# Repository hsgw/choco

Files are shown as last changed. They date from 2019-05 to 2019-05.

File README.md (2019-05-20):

# CHOCO

choco

7x4 ortholinear onehanded keyboard/macropad.   

- kailh choc switch (pg1350)
- USB type-c
- STM32F072C8T6
- QMK Firmware - https://github.com/hsgw/qmk_firmware/tree/choco

## BUILD
### Cut mounting leg (SW_CHOC6)
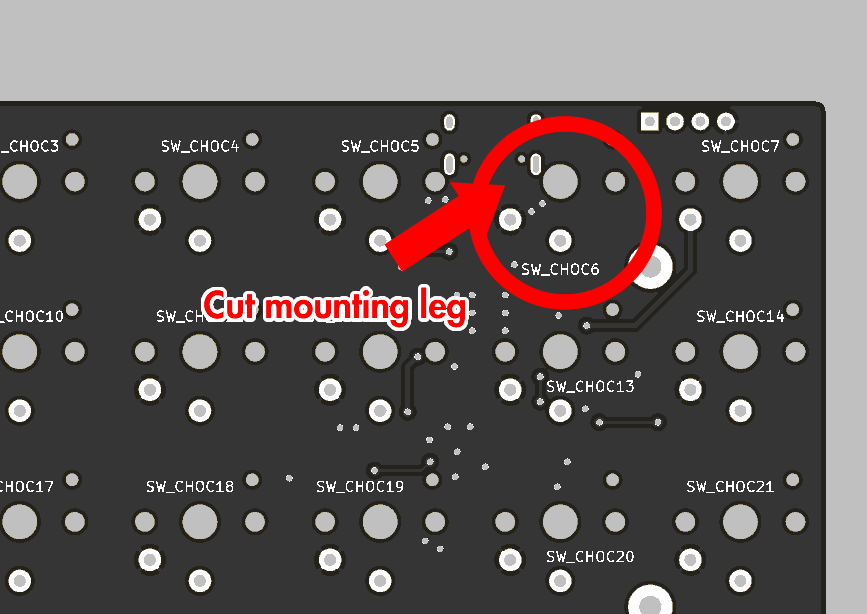
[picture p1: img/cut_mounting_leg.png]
cut_mounting_leg


### How to enter bootloader
1. Push and hold reset switch
2. Push and hold boot switch (SW_CHOC7 / right upper corner switch)
3. Release reset switch
4. Release boot switch

### Firmware
QMK Firmware - https://github.com/hsgw/qmk_firmware/tree/choco

## License
MIT license   
(c)2019 Takuya Urakawa, Dm9Records

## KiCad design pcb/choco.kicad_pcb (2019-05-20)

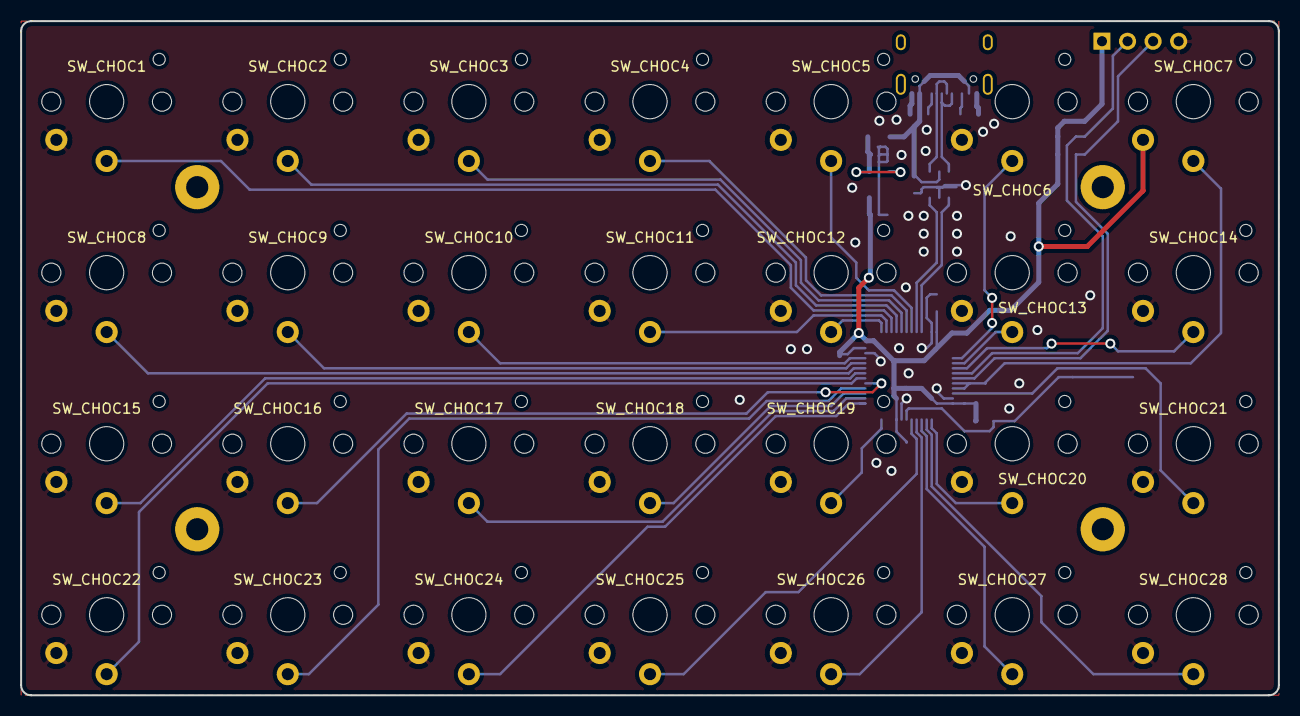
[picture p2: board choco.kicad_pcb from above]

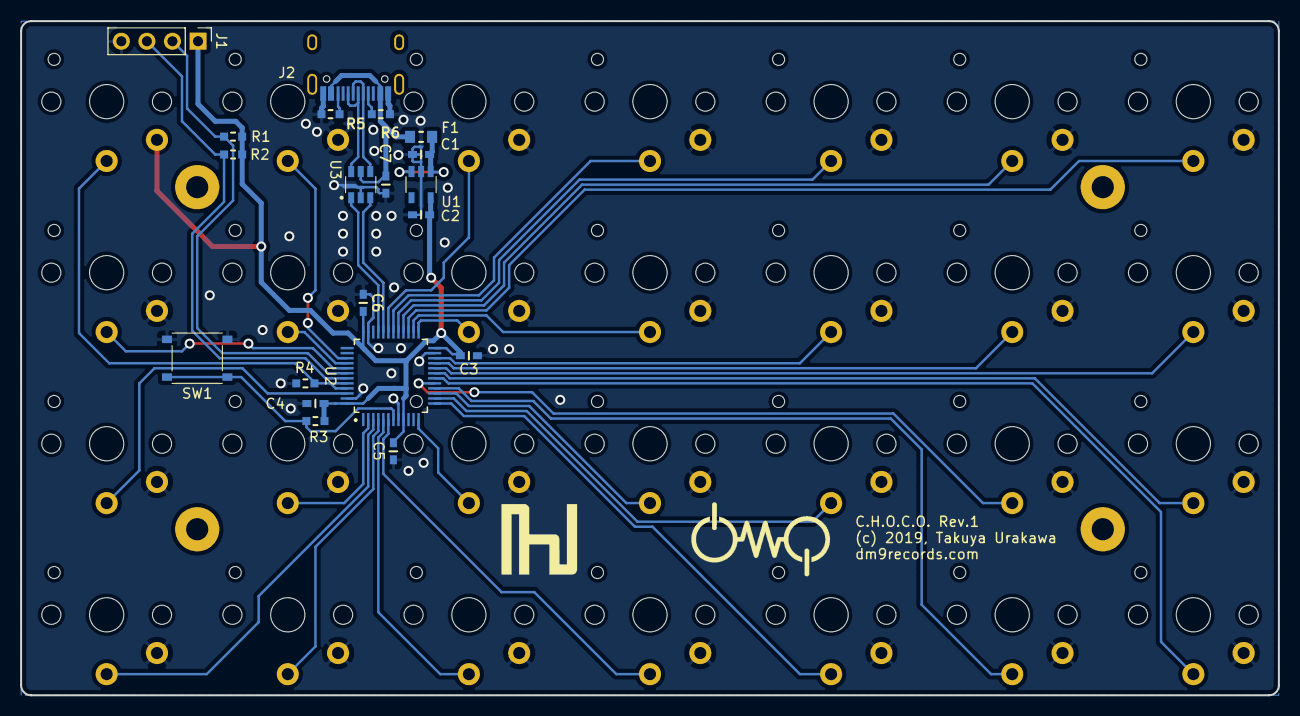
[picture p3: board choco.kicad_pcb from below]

Board: 2 copper layers, 125.0 x 67.0 mm, 48 parts (20 on the bottom side), 41 nets.

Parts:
C1, C2: 1u; C1608_Hand
C3, C4, C5, C6, C7: 0.1u; C1608_Hand
F1: 100mA; C2012_hand
J1: Conn_01x04; Socket_Strip_Straight_1x04_Pitch2.54mm
J2: USB_C_12pin_Receptacle; HRO-TYPE-C-31-M-12-Assembly
R1, R2: I2C; R1608_Hand
R3, R4: 10k; R1608_Hand
R5, R6: 5.1k; R1608_Hand
SW1: SW_Push; TACT_5.1x5.1
SW_CHOC1, SW_CHOC2, SW_CHOC3, SW_CHOC4, SW_CHOC5, SW_CHOC6, SW_CHOC7, SW_CHOC8, SW_CHOC9, SW_CHOC10, SW_CHOC11, SW_CHOC12, SW_CHOC13, SW_CHOC14, SW_CHOC15, SW_CHOC16, SW_CHOC17, SW_CHOC18, SW_CHOC19, SW_CHOC20, SW_CHOC21, SW_CHOC22, SW_CHOC23, SW_CHOC24, SW_CHOC25, SW_CHOC26, SW_CHOC27, SW_CHOC28: SW_Push; SW_kailh_pg1350_1u
U1: TLV73333PDBVR; SOT-23-5
U2: STM32F072C8Tx; LQFP-48_7x7mm_Pitch0.5mm
U3: USBLC6-2SC6; SOT-23-6

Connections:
+3V3: C2.1, C3.1, C4.1, C5.1, C6.1, J1.1, R1.1, R2.1, R3.1, SW_CHOC7.2, U1.5, U2.9, U2.24, U2.36, U2.48
/BOOT: R4.1, SW_CHOC7.1, U2.44, U2.45
/I2C_SCL: J1.2, R1.2, U2.42
/I2C_SDA: J1.3, R2.2, U2.43
/SW1: SW_CHOC1.1, U2.27
/SW2: SW_CHOC2.1, U2.28
/SW3: SW_CHOC3.1, U2.29
/SW4: SW_CHOC4.1, U2.30
/SW5: SW_CHOC5.1, U2.31
/SW6: SW_CHOC6.1, U2.39
/SW8: SW_CHOC8.1, U2.20
/SW9: SW_CHOC9.1, U2.21
/SW10: SW_CHOC10.1, U2.22
/SW11: SW_CHOC11.1, U2.26
/SW12: SW_CHOC12.1, U2.25
/SW13: SW_CHOC13.1, U2.40
/SW14: SW_CHOC14.1, U2.41
/SW15: SW_CHOC15.1, U2.19
/SW16: SW_CHOC16.1, U2.17
/SW17: SW_CHOC17.1, U2.14
/SW18: SW_CHOC18.1, U2.15
/SW19: SW_CHOC19.1, U2.12
/SW20: SW_CHOC20.1, U2.2
/SW21: SW_CHOC21.1, U2.46
/SW22: SW_CHOC22.1, U2.18
/SW23: SW_CHOC23.1, U2.16
/SW24: SW_CHOC24.1, U2.13
/SW25: SW_CHOC25.1, U2.6
/SW26: SW_CHOC26.1, U2.5
/SW27: SW_CHOC27.1, U2.4
/SW28: SW_CHOC28.1, U2.3
/USB_D+: U2.33, U3.1
/USB_D-: U2.32, U3.3
/USB_IN_D+: J2.A6, J2.B6, U3.6
/USB_IN_D-: J2.A7, J2.B7, U3.4
GND: C1.2, C2.2, C3.2, C4.2, C5.2, C6.2, C7.2, J1.4, J2.A1_B12, J2.B1_A12, R4.2, R5.2, R6.2, SW1.1, SW_CHOC1.2, SW_CHOC2.2, SW_CHOC3.2, SW_CHOC4.2, SW_CHOC5.2, SW_CHOC6.2, SW_CHOC8.2, SW_CHOC9.2, SW_CHOC10.2, SW_CHOC11.2, SW_CHOC12.2, SW_CHOC13.2, SW_CHOC14.2, SW_CHOC15.2, SW_CHOC16.2, SW_CHOC17.2, SW_CHOC18.2, SW_CHOC19.2, SW_CHOC20.2, SW_CHOC21.2, SW_CHOC22.2, SW_CHOC23.2, SW_CHOC24.2, SW_CHOC25.2, SW_CHOC26.2, SW_CHOC27.2, SW_CHOC28.2, U1.2, U2.8, U2.23, U2.35, U2.47, U3.2
unnamed: C1.1, F1.1, U1.1, U1.3
unnamed: J2.A5, R6.1
unnamed: J2.B5, R5.1
unnamed: R3.2, SW1.2, U2.7
VBUS: C7.1, F1.2, J2.A4_B9, J2.A9_B4, U3.5
